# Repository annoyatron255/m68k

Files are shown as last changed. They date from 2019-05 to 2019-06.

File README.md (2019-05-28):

# m68k
A [Motorola 68000](https://en.wikipedia.org/wiki/Motorola_68000) computer. It uses a Lattice FPGA to control the CPU and interface with the peripherals. It is designed to be standalone, with a PS/2 port for input and a VGA port for display output. 
## Contributors
* [Avery Bartnik](https://github.com/Jythonscript)
  * [Assembly Programming](https://github.com/annoyatron255/m68k/blob/master/src/init.s)
  * README
* [Erik Duxstad](https://github.com/eduxstad)
  * Schematic
  * PCB Layout
  * Ordering PCB
* [Jack Sweeney](https://github.com/annoyatron255)
  * Schematic
  * Assembly Programming
  * FPGA Verilog
  * Simulation
* [Michael Wagner](https://github.com/MDW01)
  * Schematic
  * PCB Layout
  * Ordering Parts
## What We Did
1. Design schematic for 68000 computer
2. Design and layout the PCB
3. Order the PCB and parts
4. Wrote Verilog HDL for the FPGA
5. Set up a RTL simulator for the whole computer design
6. Wrote an assembly program in the simulator that displays text using the serial port
## What We Will Do
1. Solder the parts to the PCB
2. Synthesize the verilog and flash to SPI Flash to configure FPGA
3. Interface with the board via the serial port
4. Run programs on real hardware!
## Long-Term Improvements
1. Enable on-board SRAM
2. Configure toolchain to allow for C programming
3. Add scheduling interrupt
4. Install Linux
5. Set up VGA peripheral
6. Set up PS/2 peripheral
7. Set up SD Card peripheral
8. Make MMU on FPGA for Linux
## Gallery
### PCB
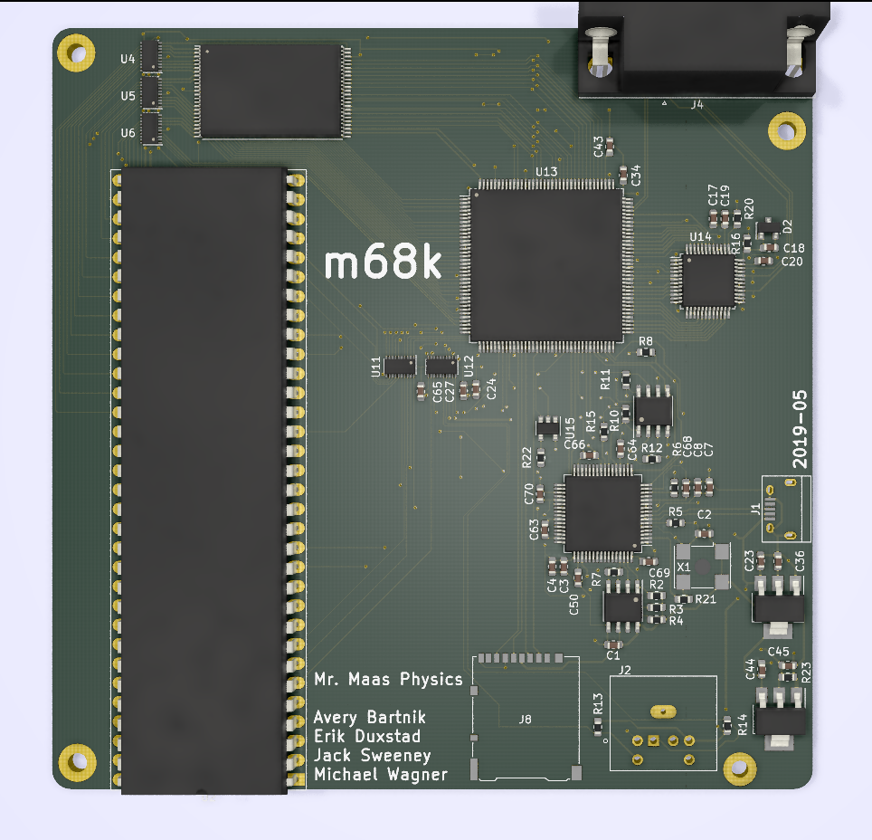
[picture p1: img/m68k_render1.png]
PCB Render Front

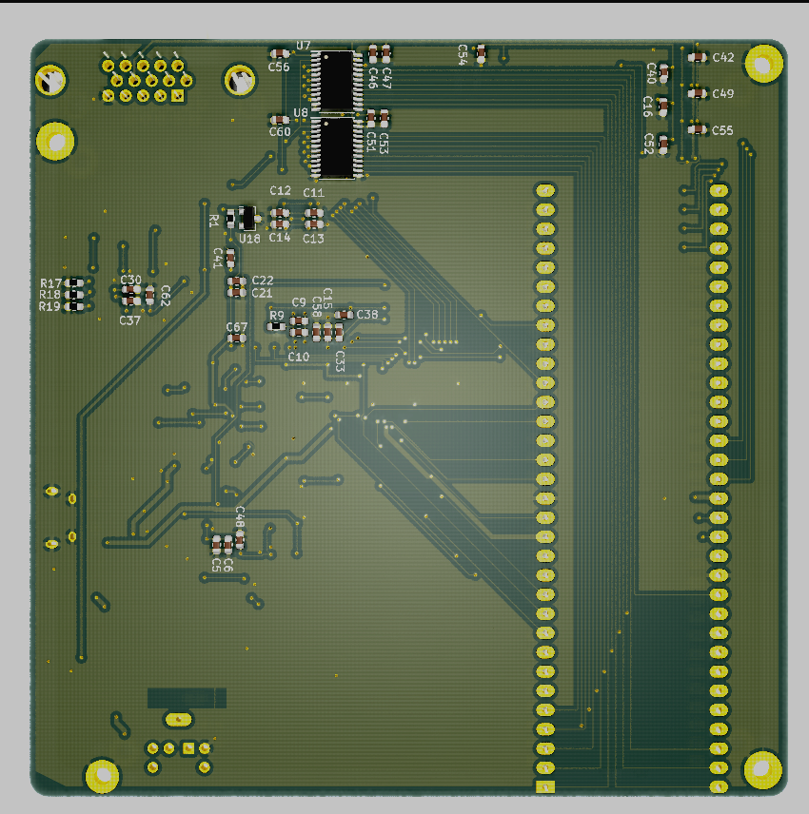
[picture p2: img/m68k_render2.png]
PCB Render Back

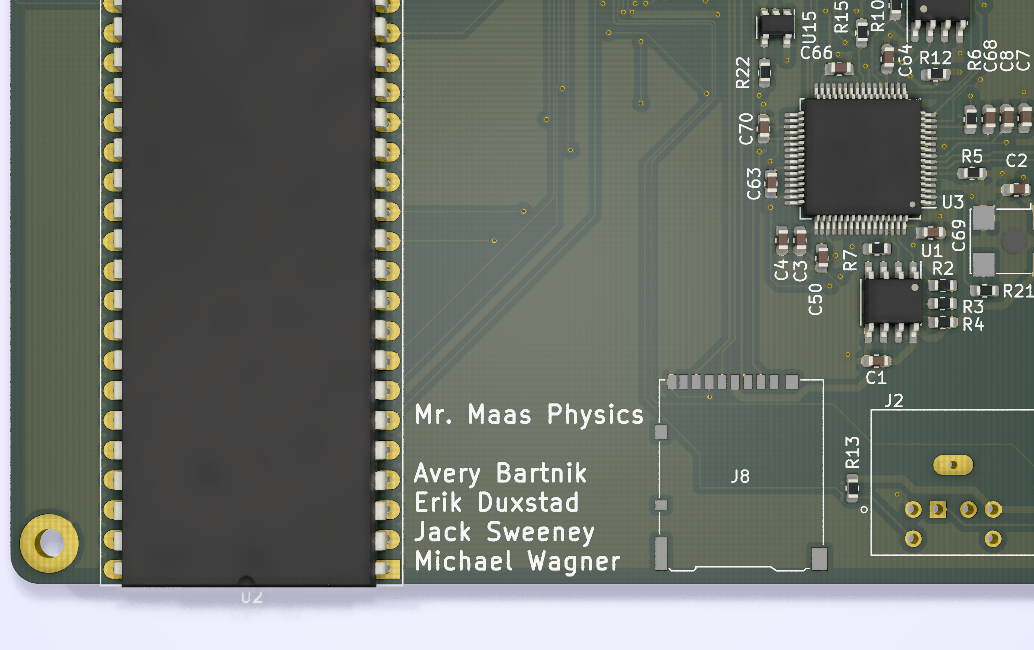
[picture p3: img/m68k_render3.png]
PCB Render Names

### PCB Layout 
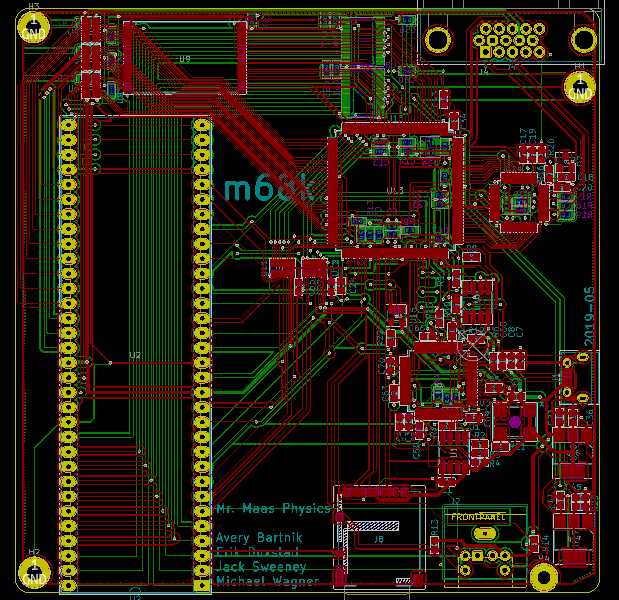
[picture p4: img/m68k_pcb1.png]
PCB Layout Editor Overview

### FPGA
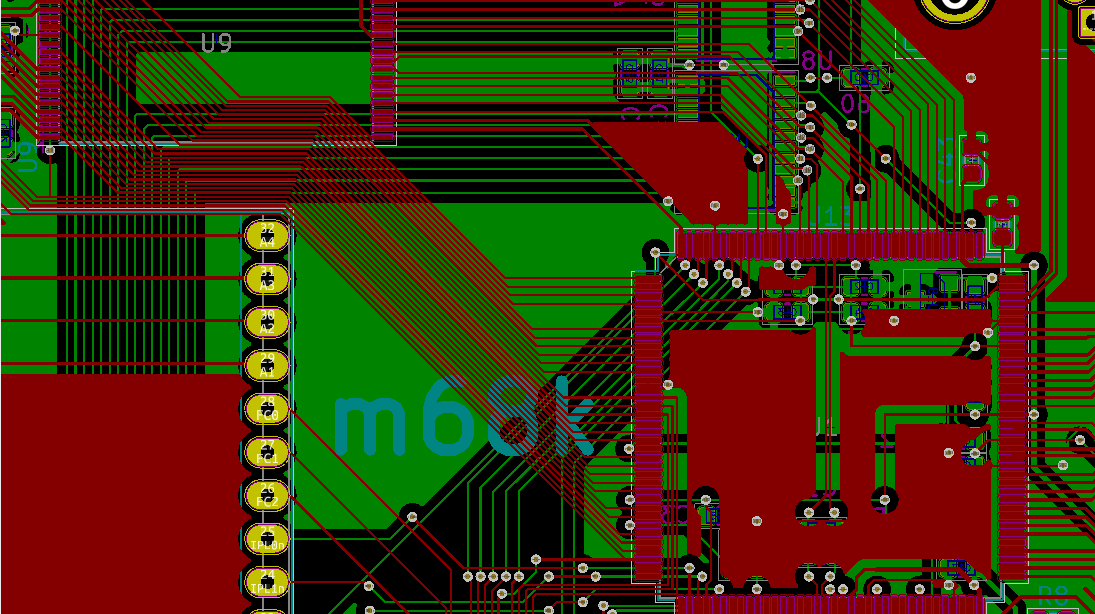
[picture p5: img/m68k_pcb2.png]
PCB Layout Editor FPGA

### SRAM
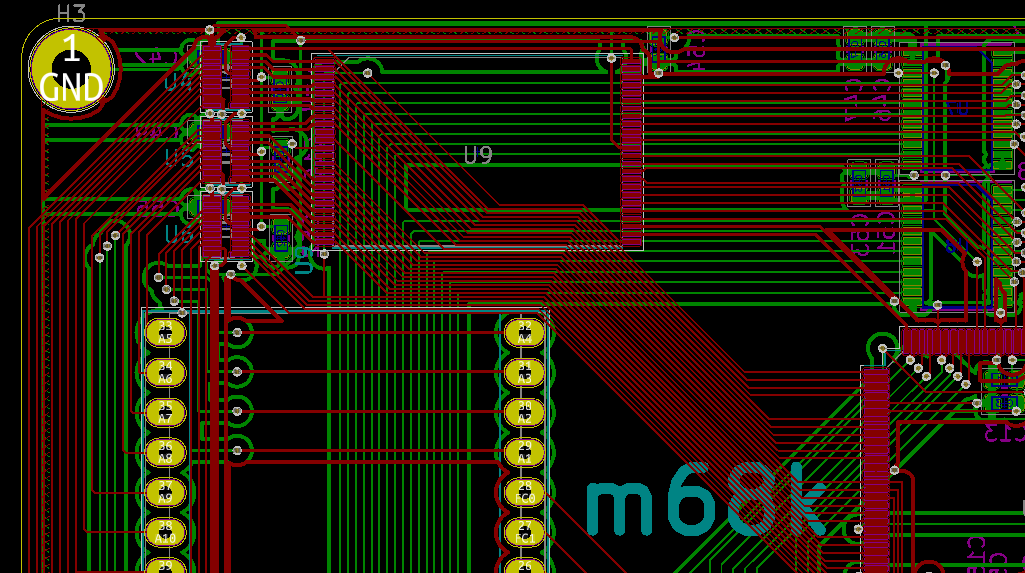
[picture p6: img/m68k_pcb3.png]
PCB Layout Editor SRAM

### Schematic
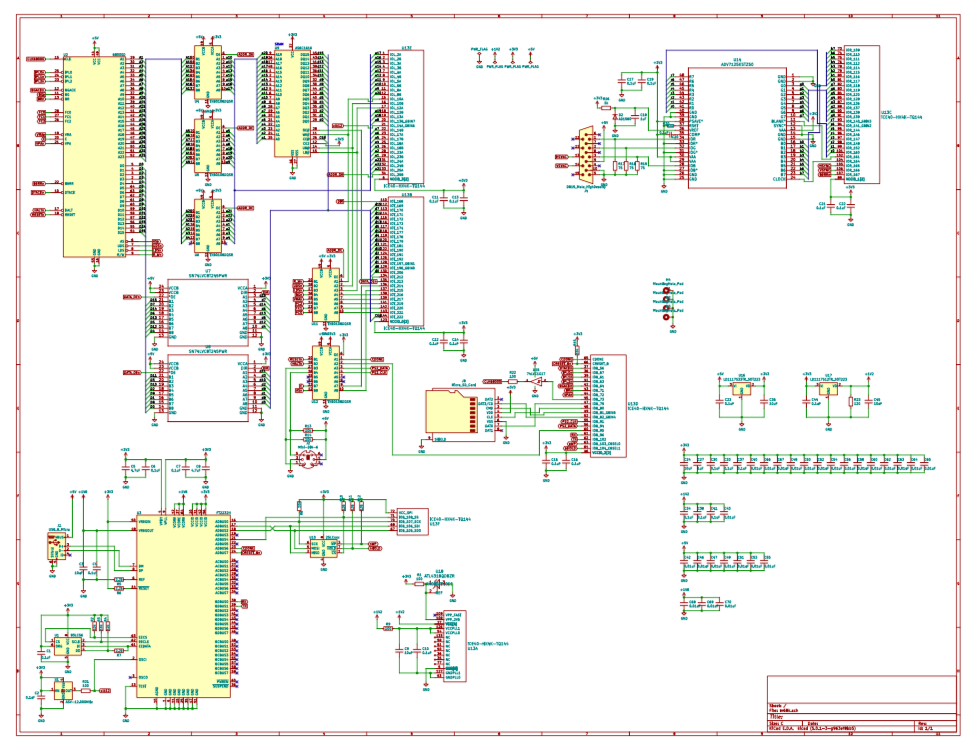
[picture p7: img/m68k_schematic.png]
PCB Schematic


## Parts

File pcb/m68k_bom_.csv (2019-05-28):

Component | Description | Value | Footprint | Quantity Per PCB | Digikey | Ordered
1 | Unpolarized capacitor | 10000 pF | 0603 | 25 | _1276-1132-1-ND_
2 | Unpolarized capacitor | 0.1uF | 0603 | 25 | _1276-1006-1-ND_
3 | Unpolarized capacitor | 10uF | 0603 | 5 | _1276-1192-1-ND_
4 | Unpolarized capacitor | 1uF | 0603 | 2 | 1276-1102-1-ND_
5 | Unpolarized capacitor | 4.7uF | 0603 | 2 | _1276-1044-1-ND_
6 | Diode | AD1580 | SOT-23 | 1 | _AD1580ARTZ-REEL7CT-ND_
7 | Micro SD Card Socket | Micro_SD_Card | DM3AT-SF-PEJM5 | 1 | _HR1964CT-ND_
8 | Mini-DIN-6 | Mini-DIN-6 | CUI_MD-60S | 1 | _CP-2460-ND_
9 | USB_B_Micro | USB_B_Micro | USB_Micro-B | 1 | _609-4618-1-ND_
10 | Resistor | 100 | 0603 | 4 | 311-100HRCT-ND
11 | Resistor | 10k | 0603 | 10 | N/A | 0
12 | Resistor | 120 | 0603 | 1 | 311-120HRCT-ND
13 | Resistor | 1k | 0603 | 1 | N/A | 0
14 | Resistor | 2.2k | 0603 | 3 | 311-2.20KHRCT-ND
15 | Resistor | 530 | 0603 | 1 | _311-536HRCT-ND_
16 | Resistor | 75 | 0603 | 3 | 311-75.0HRCT-ND
17 | SPI Serial EEPROM, DIP-8/SOIC-8/TSSOP-8 | 25LCxxx | SOIC-8_3.9x4.9mm_P1.27mm | 1 | _W25Q128JVSIMCT-ND_
18 | 68000D | 68000D | DIP-64_W22.86mm_Socket_LongPads | 1 | N/A | 0
19 | Single Schmitt Buffer Gate, Low-Voltage CMOS | 74LVC1G17 | SOT-23-5 | 1 | _296-35948-1-ND_
20 | Serial EEPROM, 93 Series, with ORG Pin, 2.5V, DIP-8/SOIC-8 | 93LC56 | SOIC-8_3.9x4.9mm_P1.27mm | 1 | _93LC56BT-I/SNCT-ND_
21 |  | ADV7125KSTZ50 | LQFP-48_7x7mm_P0.5mm | 1 | _ADV7125KSTZ50-ND_
22 |  | AS6C1616 | TSOP-I-48_18.4x12mm_P0.5mm | 1 | _1450-1022-ND_
23 |  | ATL431BQDBZR | SOT-23 | 1 | _296-44371-1-ND_
24 | FT2232Hx, Hi Speed Double Channel USB UART/FIFO, LQFP/QFN-64 | FT2232H | LQFP-64_10x10mm_P0.5mm | 1 | _768-1347-ND_
25 | 800mA Fixed Low Drop Positive Voltage Regulator, Fixed Output 1.2V, SOT-223 | LD1117S12TR_SOT223 | SOT-223-3_TabPin2 | 1 | _497-4240-1-ND_
26 | 800mA Fixed Low Drop Positive Voltage Regulator, Fixed Output 3.3V, SOT-223 | LD1117S33TR_SOT223 | SOT-223-3_TabPin2 | 1 | _497-1242-1-ND_
27 |  | SN74LVC8T245PWR | TSSOP-24_4.4x7.8mm_P0.65mm | 2 | _296-18593-1-ND_
28 |  | TXB0108DQSR | USON-20_2x4mm_P0.4mm | 5 | _296-27217-1-ND_
29 |  | iCE40-HX4K-TQ144 | TQFP-144_20x20mm_P0.5mm | 1 | _220-1572-ND_
30 | 3.3V HCMOS SMD Crystal Clock Oscillator, Abracon | ASV-12.000MHz | Oscillator_SMD_Abracon_ASV-4Pin_7.0x5.1mm | 1 | _535-9309-1-ND_

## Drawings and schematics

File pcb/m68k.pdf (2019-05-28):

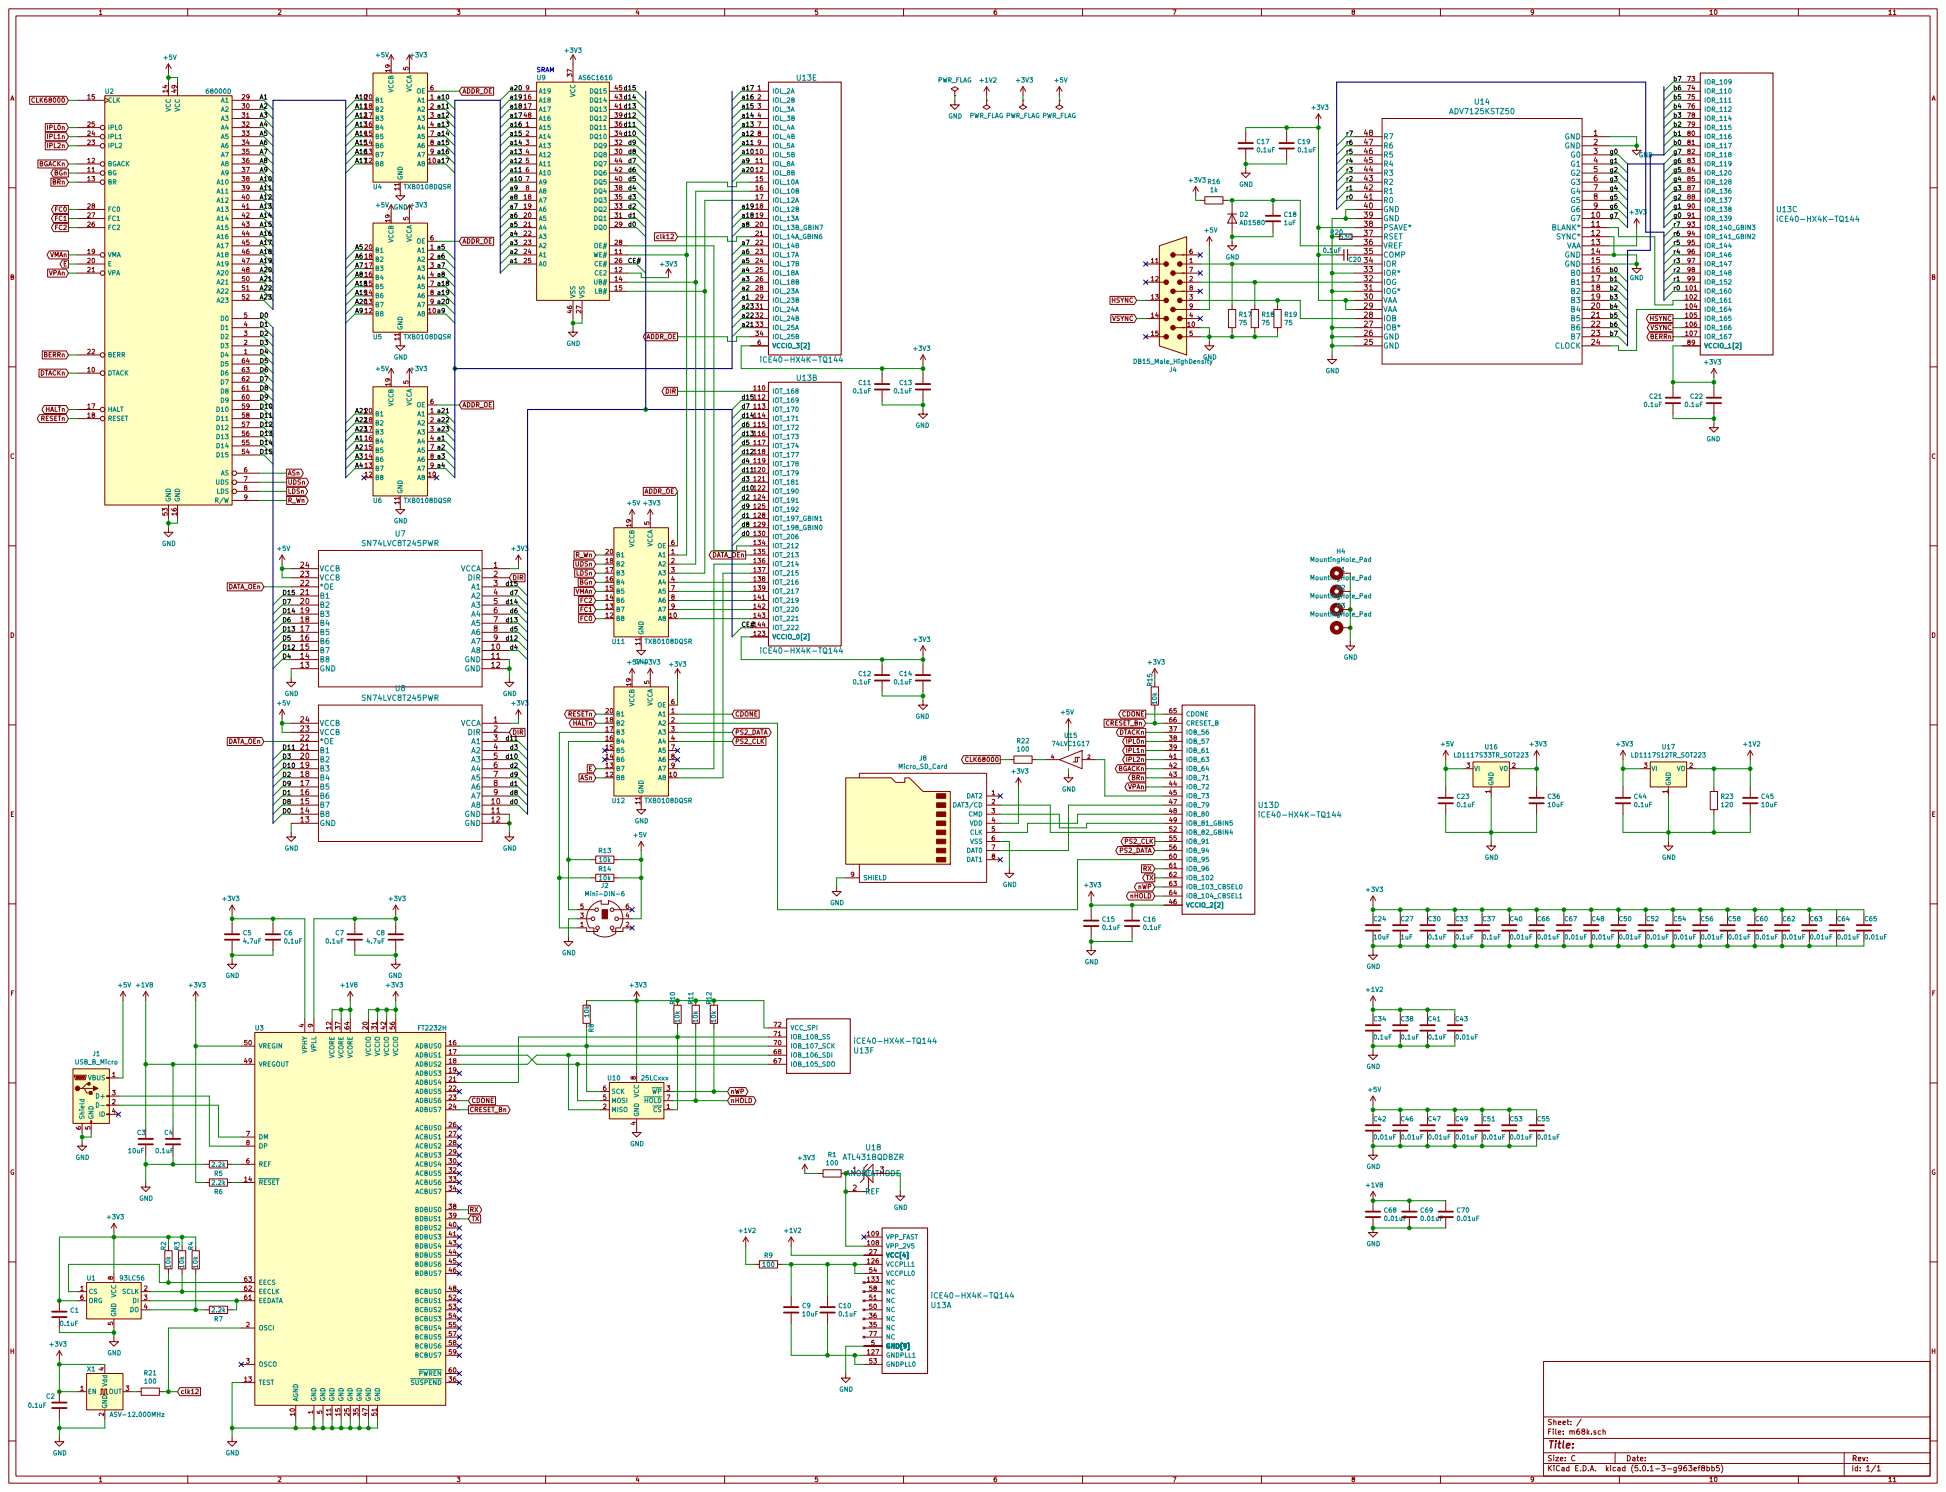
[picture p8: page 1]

IPL2n BGACKn BGn BRn FC0 FC1 FC2 VMAnE

1 AGND 10 GND 11 VCORE 12 TEST 13 RESET 14 GND 15 ADBUS0 16 ADBUS1 17 ADBUS2 18 ADBUS3 19 OSCI 2 VCCIO 20 ADBUS4 21 ADBUS5 22 ADBUS6 23 ADBUS7 24 GND 25 ACBUS0 26 ACBUS1 27 ACBUS2 28 ACBUS3 29 OSCO 3 ACBUS4 30 VCCIO 31 ACBUS5 32 ACBUS6 33 ACBUS7 34 GND 35 SUSPEND 36 VCORE 37 BDBUS0 38 BDBUS1 39 VPHY

4 BDBUS2 40 BDBUS3 41 VCCIO 42 BDBUS4 43 BDBUS5 44 BDBUS6 45 BDBUS7 46 GND 47 BCBUS0 48 VREGOUT 49 GND

5 VREGIN 50 GND 51 BCBUS1 52 BCBUS2 53 BCBUS3 54 BCBUS4 55 VCCIO 56 BCBUS5 57 BCBUS6 58 BCBUS7 59 REF 6 PWREN 60 EEDATA 61 EECLK 62 EECS 63 VCORE 64 DM 7 DP 8 VPLL

4 MOSI 5 SCK 6 HOLD VCC 7 U10 8

Id: 1/1 Title: File: m68k.sch Sheet: /

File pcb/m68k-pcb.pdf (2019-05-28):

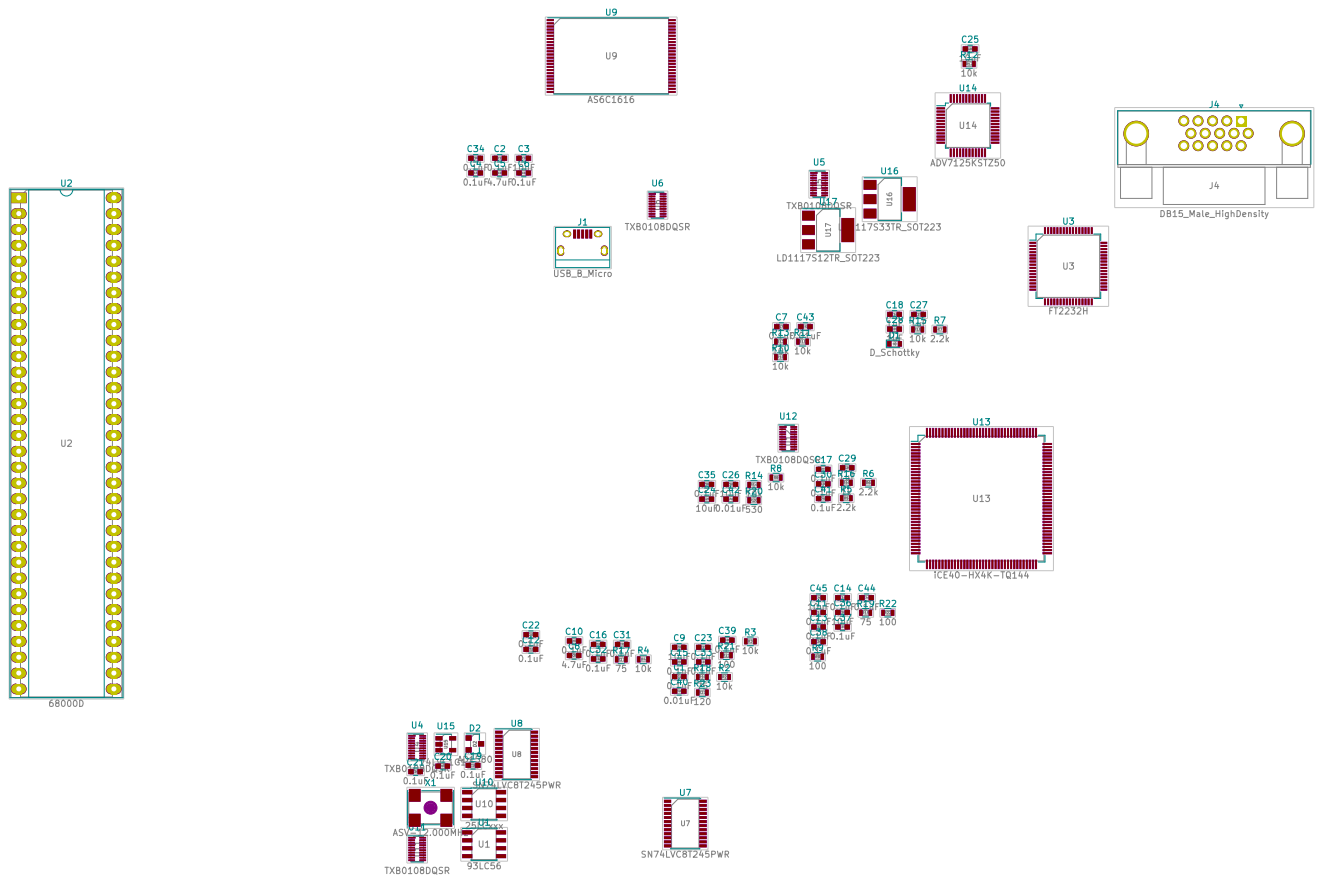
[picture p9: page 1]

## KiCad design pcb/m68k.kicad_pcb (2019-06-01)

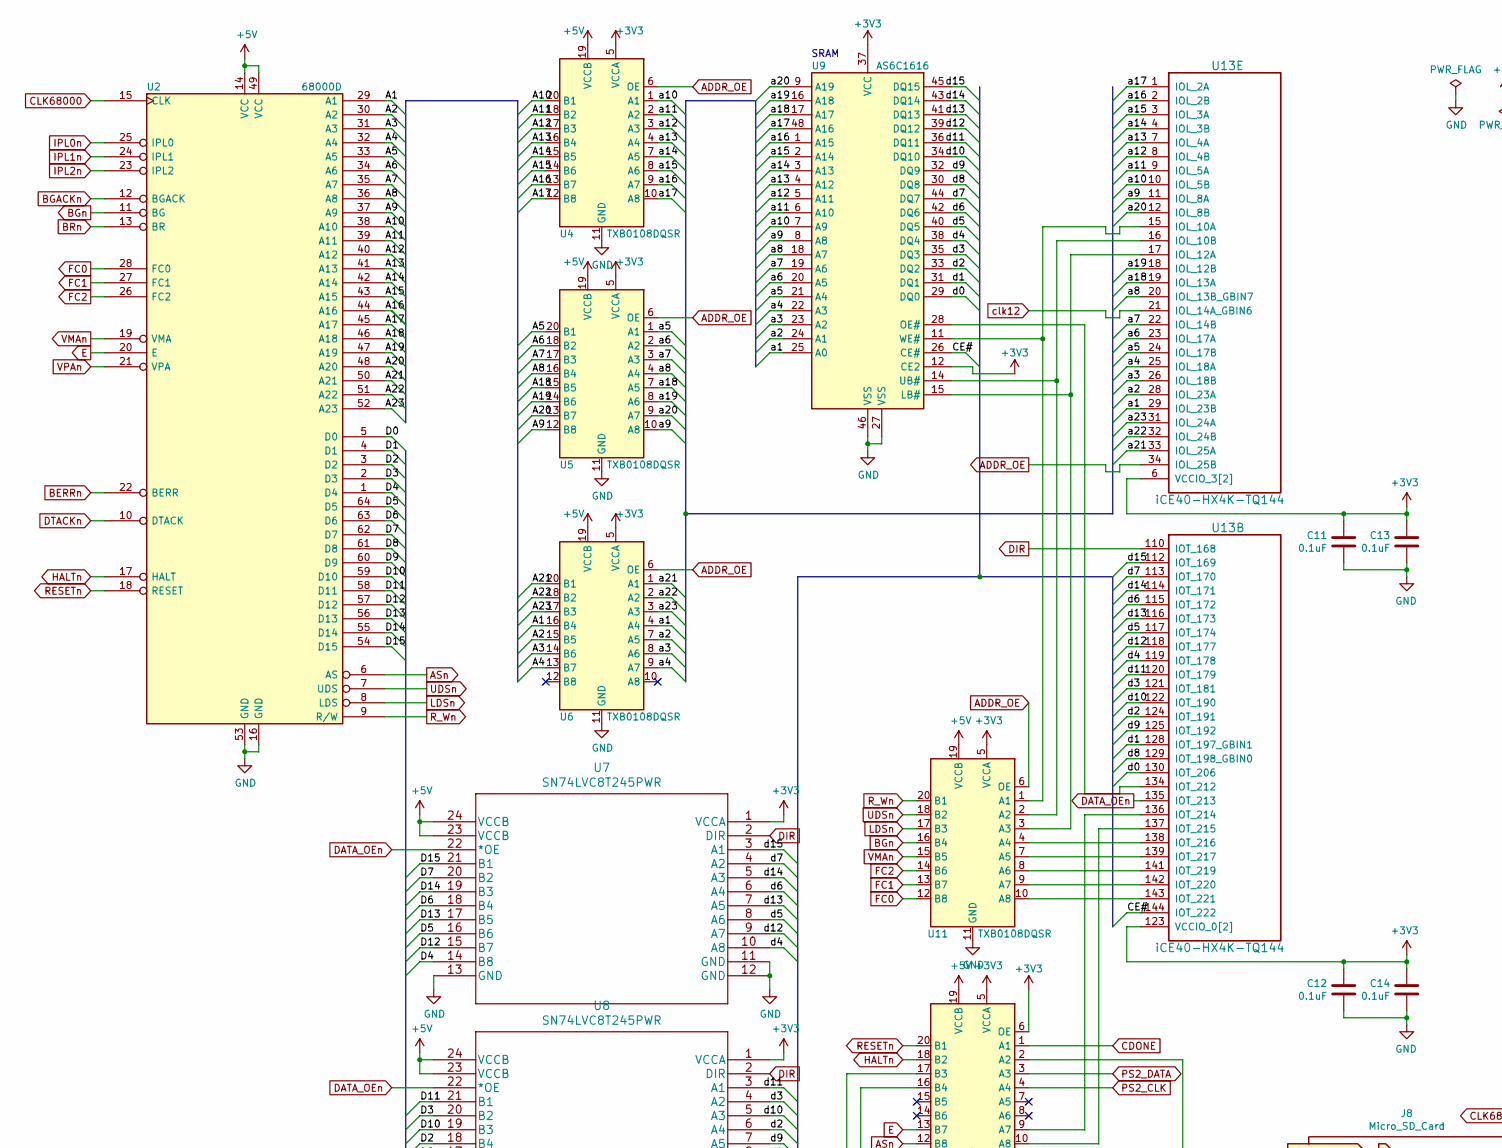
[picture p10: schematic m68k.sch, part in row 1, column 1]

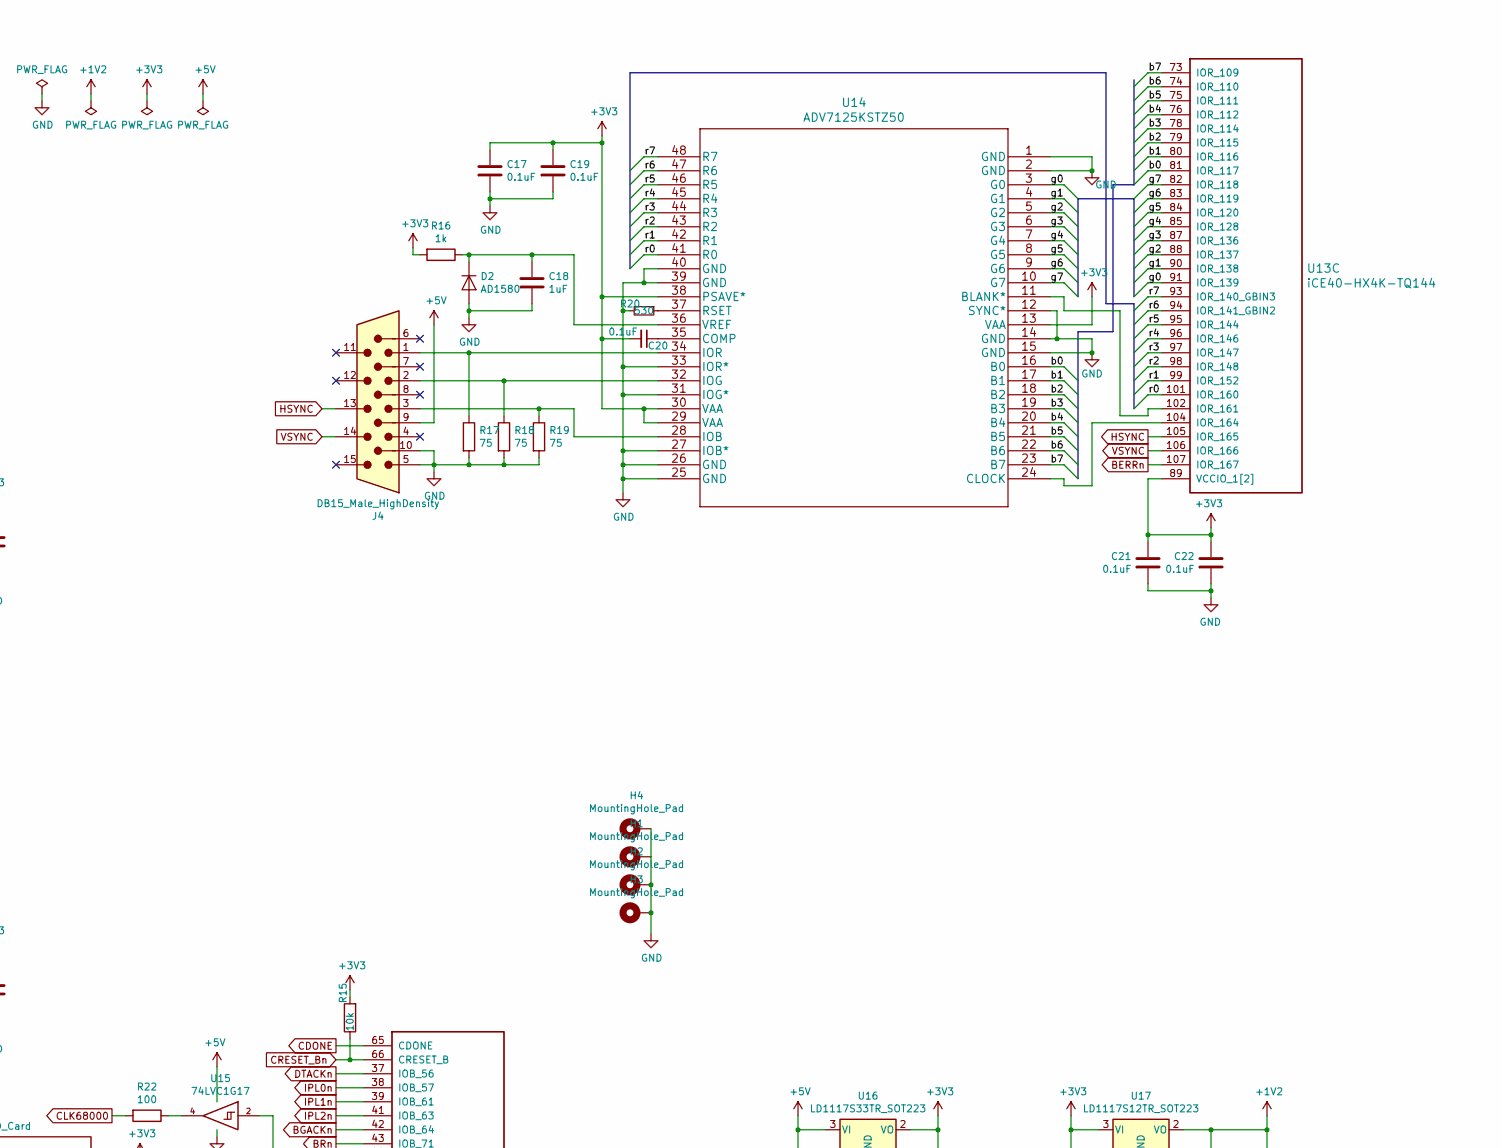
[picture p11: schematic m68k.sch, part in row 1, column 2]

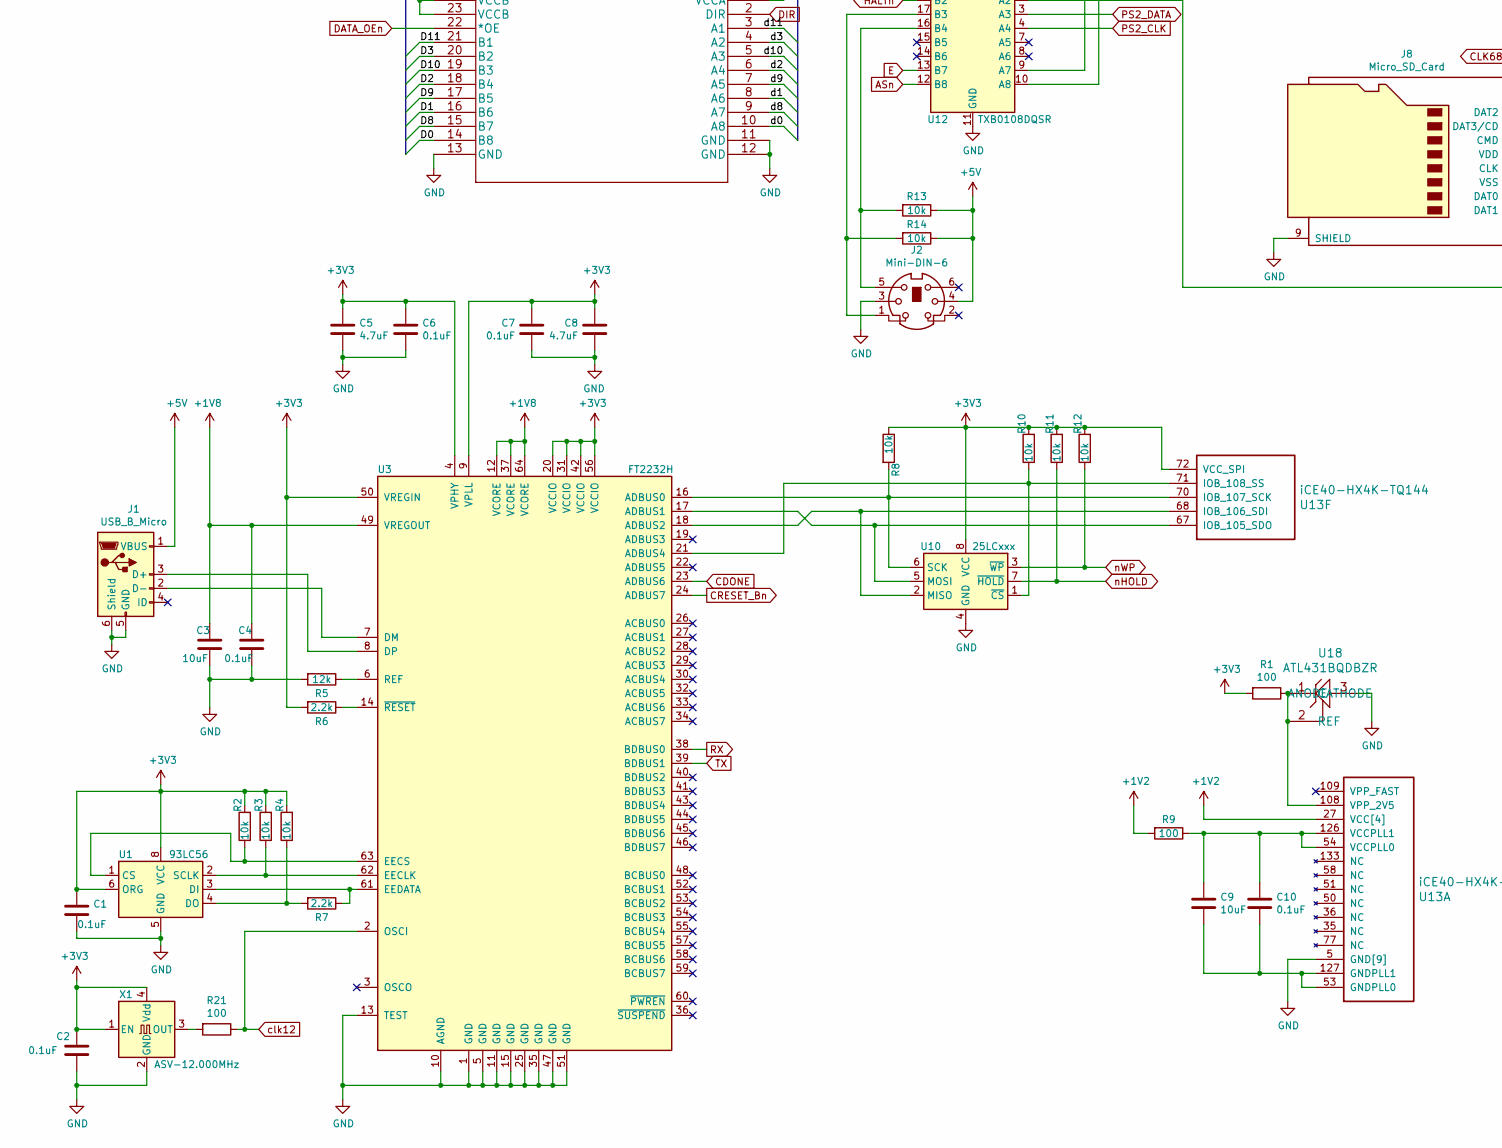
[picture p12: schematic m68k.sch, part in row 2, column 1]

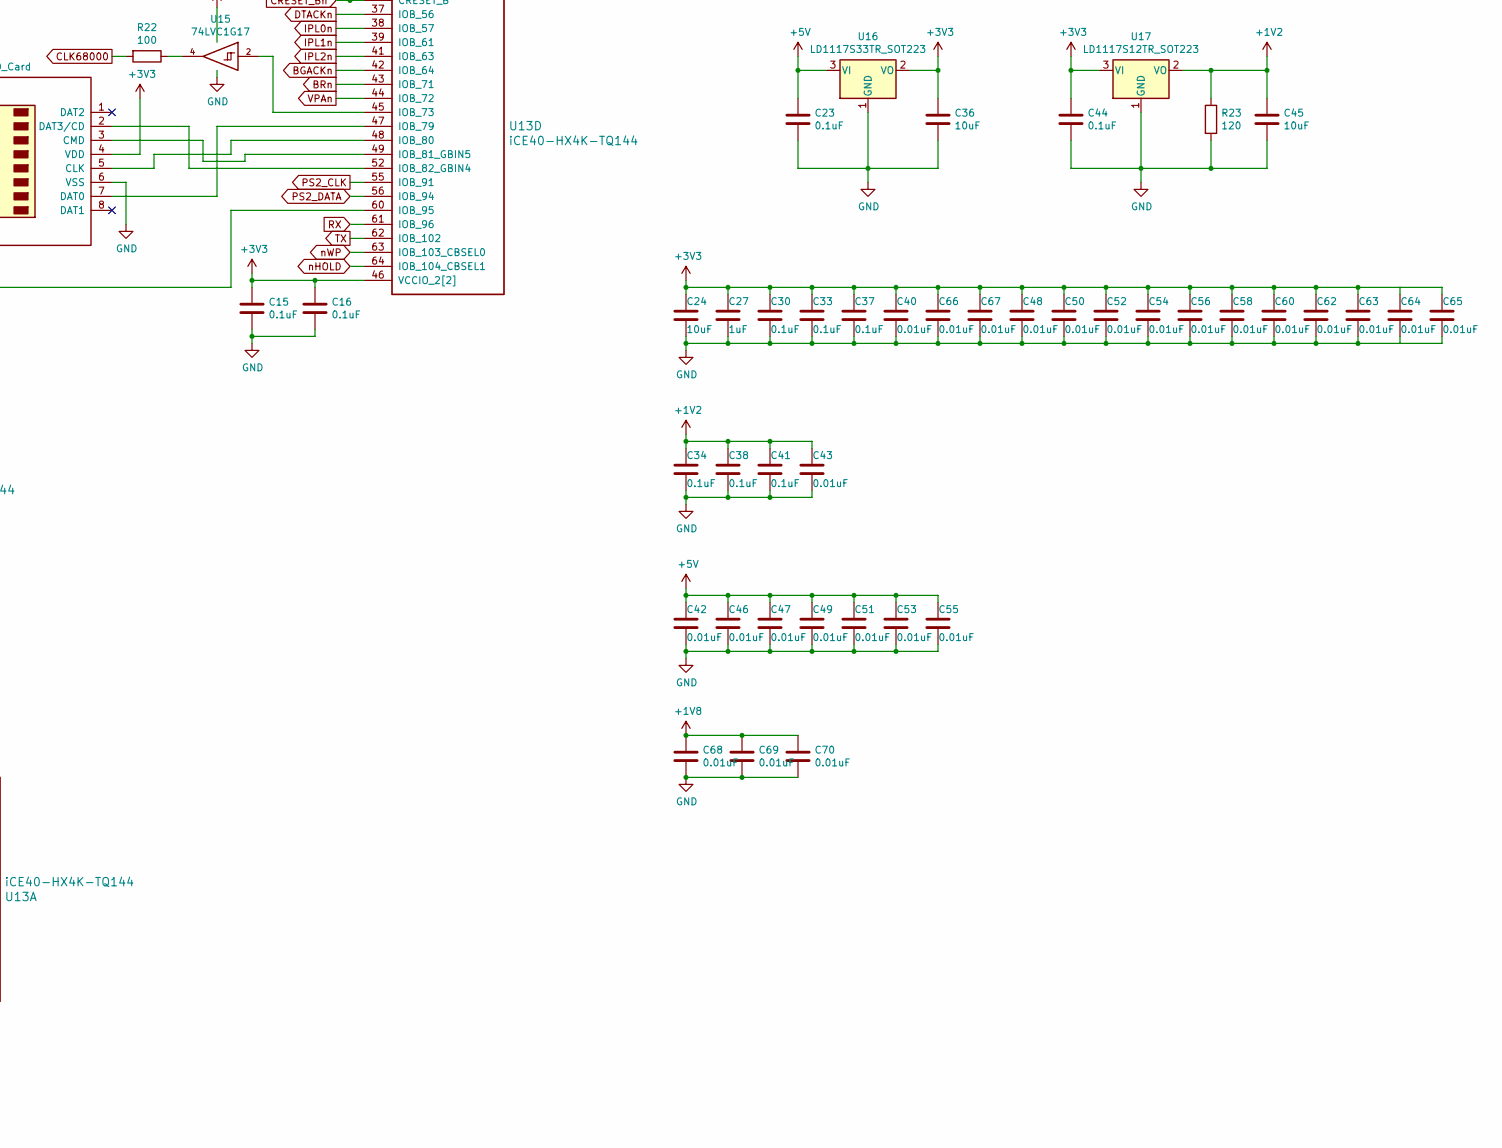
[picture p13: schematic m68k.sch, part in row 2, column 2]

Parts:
C1, C2, C4, C6, C7, C10, C11, C12, C13, C14, C15, C16, C17, C19, C20, C21, C22, C23, C30, C33, C34, C37, C38, C41, C44: 0.1uF; C_0603_1608Metric
C3, C9, C24, C36, C45: 10uF; C_0603_1608Metric
C5, C8: 4.7uF; C_0603_1608Metric
C18, C27: 1uF; C_0603_1608Metric
C40, C42, C43, C46, C47, C48, C49, C50, C51, C52, C53, C54, C55, C56, C58, C60, C62, C63, C64, C65, C66, C67, C68, C69, C70: 0.01uF; C_0603_1608Metric
D2: AD1580; SOT-23
H1, H2, H3, H4: MountingHole_Pad; MountingHole_2.5mm_Pad
J1: USB_B_Micro; USB_Micro-B
J2: Mini-DIN-6; CUI_MD-60S
J4: DB15_Male_HighDensity; DSUB-15-HD_Female_Horizontal_P2.29x1.98mm_EdgePinOffset3.03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
J8: Micro_SD_Card; microSD_HC_Hirose_DM3AT-SF-PEJM5
R1, R9, R21, R22: 100; R_0603_1608Metric
R2, R3, R4, R8, R10, R11, R12, R13, R14, R15: 10k; R_0603_1608Metric
R5: 12k; R_0603_1608Metric
R6, R7: 2.2k; R_0603_1608Metric
R16: 1k; R_0603_1608Metric
R17, R18, R19: 75; R_0603_1608Metric
R20: 530; R_0603_1608Metric
R23: 120; R_0603_1608Metric
U1: 93LC56; SOIC-8_3.9x4.9mm_P1.27mm
U2: 68000D; DIP-64_W22.86mm_Socket_LongPads
U3: FT2232H; LQFP-64_10x10mm_P0.5mm
U4, U5, U6, U11, U12: TXB0108DQSR; USON-20_2x4mm_P0.4mm
U7, U8: SN74LVC8T245PWR; TSSOP-24_4.4x7.8mm_P0.65mm
U9: AS6C1616; TSOP-I-48_18.4x12mm_P0.5mm
U10: 25LCxxx; SOIC-8_3.9x4.9mm_P1.27mm
U13: iCE40-HX4K-TQ144; TQFP-144_20x20mm_P0.5mm
U14: ADV7125KSTZ50; LQFP-48_7x7mm_P0.5mm
U15: 74LVC1G17; SOT-23-5
U16: LD1117S33TR_SOT223; SOT-223-3_TabPin2
U17: LD1117S12TR_SOT223; SOT-223-3_TabPin2
U18: ATL431BQDBZR; SOT-23
X1: ASV-12.000MHz; Oscillator_SMD_Abracon_ASV-4Pin_7.0x5.1mm

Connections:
+1V2: C34.1, C38.1, C41.1, C43.1, C45.1, R9.2, R23.1, U13.27 (VCC[4]), U13.40 (VCC[4]), U13.92 (VCC[4]), U13.111 (VCC[4]), U17.2 (VO)
+1V8: C3.1, C4.1, C68.1, C69.1, C70.1, U3.12 (VCORE), U3.37 (VCORE), U3.49 (VREGOUT), U3.64 (VCORE)
+3V3: C1.1, C2.1, C5.1, C6.1, C7.1, C8.1, C11.1, C12.1, C13.1, C14.1, C15.1, C16.1, C17.1, C19.1, C20.2, C21.1, C22.1, C24.1, C27.1, C30.1, C33.1, C36.1, C37.1, C40.1, C44.1, C48.1, C50.1, C52.1, C54.1, C56.1, C58.1, C60.1, C62.1, C63.1, C64.1, C65.1, C66.1, C67.1, J8.4 (VDD), R1.2, R2.2, R3.2, R4.2, R6.2, R8.1, R10.2, R11.2, R12.2, R15.2, R16.2, U1.6 (ORG), U1.8 (VCC), U3.4 (VPHY), U3.9 (VPLL), U3.20 (VCCIO), U3.31 (VCCIO), U3.42 (VCCIO), U3.50 (VREGIN), U3.56 (VCCIO), U4.5 (VCCA), U5.5 (VCCA), U6.5 (VCCA), U7.1 (VCCA), U8.1 (VCCA), U9.12 (CE2), U9.37 (VCC), U10.8 (VCC), U11.5 (VCCA), U12.5 (VCCA), U12.6 (OE), U13.6 (VCCIO_3[2]), U13.30 (VCCIO_3[2]), U13.46 (VCCIO_2[2]), U13.57 (VCCIO_2[2]), U13.72 (VCC_SPI), U13.89 (VCCIO_1[2]), U13.100 (VCCIO_1[2]), U13.123 (VCCIO_0[2]), U13.131 (VCCIO_0[2]), U14.13 (VAA), U14.29 (VAA), U14.30 (VAA), U14.38 (PSAVE*), U16.2 (VO), U17.3 (VI), X1.1 (EN), X1.4 (Vdd)
+5V: C23.1, C42.1, C46.1, C47.1, C49.1, C51.1, C53.1, C55.1, J1.1 (VBUS), J2.4, J4.9, R13.1, R14.1, U2.14 (VCC), U2.49 (VCC), U4.19 (VCCB), U5.19 (VCCB), U6.19 (VCCB), U7.23 (VCCB), U7.24 (VCCB), U8.23 (VCCB), U8.24 (VCCB), U11.19 (VCCB), U12.19 (VCCB), U15.5 (VCC), U16.3 (VI)
/A1: U2.29 (A1), U6.16 (B4)
/A2: U2.30 (A2), U6.15 (B5)
/A3: U2.31 (A3), U6.14 (B6)
/A4: U2.32 (A4), U6.13 (B7)
/A5: U2.33 (A5), U5.20 (B1)
/A6: U2.34 (A6), U5.18 (B2)
/A7: U2.35 (A7), U5.17 (B3)
/A8: U2.36 (A8), U5.16 (B4)
/A9: U2.37 (A9), U5.12 (B8)
/A10: U2.38 (A10), U4.20 (B1)
/A11: U2.39 (A11), U4.18 (B2)
/A12: U2.40 (A12), U4.17 (B3)
/A13: U2.41 (A13), U4.16 (B4)
/A14: U2.42 (A14), U4.15 (B5)
/A15: U2.43 (A15), U4.14 (B6)
/A16: U2.44 (A16), U4.13 (B7)
/A17: U2.45 (A17), U4.12 (B8)
/A18: U2.46 (A18), U5.15 (B5)
/A19: U2.47 (A19), U5.14 (B6)
/A20: U2.48 (A20), U5.13 (B7)
/A21: U2.50 (A21), U6.20 (B1)
/A22: U2.51 (A22), U6.18 (B2)
/A23: U2.52 (A23), U6.17 (B3)
/CE#: U9.26 (CE#), U13.144 (IOT_222)
/D0: U2.5 (D0), U8.14 (B8)
/D1: U2.4 (D1), U8.16 (B6)
/D2: U2.3 (D2), U8.18 (B4)
/D3: U2.2 (D3), U8.20 (B2)
/D4: U2.1 (D4), U7.14 (B8)
/D5: U2.64 (D5), U7.16 (B6)
/D6: U2.63 (D6), U7.18 (B4)
/D7: U2.62 (D7), U7.20 (B2)
/D8: U2.61 (D8), U8.15 (B7)
/D9: U2.60 (D9), U8.17 (B5)
/D10: U2.59 (D10), U8.19 (B3)
/D11: U2.58 (D11), U8.21 (B1)
/D12: U2.57 (D12), U7.15 (B7)
/D13: U2.56 (D13), U7.17 (B5)
/D14: U2.55 (D14), U7.19 (B3)
/D15: U2.54 (D15), U7.21 (B1)
/a1: U6.4 (A4), U9.25 (A0), U13.29 (IOL_23B)
/a2: U6.7 (A5), U9.24 (A1), U13.28 (IOL_23A)
/a3: U6.8 (A6), U9.23 (A2), U13.26 (IOL_18B)
/a4: U6.9 (A7), U9.22 (A3), U13.25 (IOL_18A)
/a5: U5.1 (A1), U9.21 (A4), U13.24 (IOL_17B)
/a6: U5.2 (A2), U9.20 (A5), U13.23 (IOL_17A)
/a7: U5.3 (A3), U9.19 (A6), U13.22 (IOL_14B)
/a8: U5.4 (A4), U9.18 (A7), U13.20 (IOL_13B_GBIN7)
/a9: U5.10 (A8), U9.8 (A8), U13.11 (IOL_8A)
/a10: U4.1 (A1), U9.7 (A9), U13.10 (IOL_5B)
/a11: U4.2 (A2), U9.6 (A10), U13.9 (IOL_5A)
/a12: U4.3 (A3), U9.5 (A11), U13.8 (IOL_4B)
/a13: U4.4 (A4), U9.4 (A12), U13.7 (IOL_4A)
/a14: U4.7 (A5), U9.3 (A13), U13.4 (IOL_3B)
/a15: U4.8 (A6), U9.2 (A14), U13.3 (IOL_3A)
/a16: U4.9 (A7), U9.1 (A15), U13.2 (IOL_2B)
/a17: U4.10 (A8), U9.48 (A16), U13.1 (IOL_2A)
/a18: U5.7 (A5), U9.17 (A17), U13.19 (IOL_13A)
/a19: U5.8 (A6), U9.16 (A18), U13.18 (IOL_12B)
/a20: U5.9 (A7), U9.9 (A19), U13.12 (IOL_8B)
/a21: U6.1 (A1), U13.33 (IOL_25A)
/a22: U6.2 (A2), U13.32 (IOL_24B)
/a23: U6.3 (A3), U13.31 (IOL_24A)
/b0: U13.81 (IOR_117), U14.16 (B0)
/b1: U13.80 (IOR_116), U14.17 (B1)
/b2: U13.79 (IOR_115), U14.18 (B2)
/b3: U13.78 (IOR_114), U14.19 (B3)
/b4: U13.76 (IOR_112), U14.20 (B4)
/b5: U13.75 (IOR_111), U14.21 (B5)
/b6: U13.74 (IOR_110), U14.22 (B6)
/b7: U13.73 (IOR_109), U14.23 (B7)
/d0: U8.10 (A8), U9.29 (DQ0), U13.130 (IOT_206)
/d1: U8.8 (A6), U9.31 (DQ1), U13.128 (IOT_197_GBIN1)
/d2: U8.6 (A4), U9.33 (DQ2), U13.124 (IOT_191)
/d3: U8.4 (A2), U9.35 (DQ3), U13.121 (IOT_181)
/d4: U7.10 (A8), U9.38 (DQ4), U13.119 (IOT_178)
/d5: U7.8 (A6), U9.40 (DQ5), U13.117 (IOT_174)
/d6: U7.6 (A4), U9.42 (DQ6), U13.115 (IOT_172)
/d7: U7.4 (A2), U9.44 (DQ7), U13.113 (IOT_170)
/d8: U8.9 (A7), U9.30 (DQ8), U13.129 (IOT_198_GBIN0)
/d9: U8.7 (A5), U9.32 (DQ9), U13.125 (IOT_192)
/d10: U8.5 (A3), U9.34 (DQ10), U13.122 (IOT_190)
/d11: U8.3 (A1), U9.36 (DQ11), U13.120 (IOT_179)
/d12: U7.9 (A7), U9.39 (DQ12), U13.118 (IOT_177)
/d13: U7.7 (A5), U9.41 (DQ13), U13.116 (IOT_173)
/d14: U7.5 (A3), U9.43 (DQ14), U13.114 (IOT_171)
/d15: U7.3 (A1), U9.45 (DQ15), U13.112 (IOT_169)
/g0: U13.91 (IOR_139), U14.3 (G0)
/g1: U13.90 (IOR_138), U14.4 (G1)
/g2: U13.88 (IOR_137), U14.5 (G2)
/g3: U13.87 (IOR_136), U14.6 (G3)
/g4: U13.85 (IOR_128), U14.7 (G4)
/g5: U13.84 (IOR_120), U14.8 (G5)
/g6: U13.83 (IOR_119), U14.9 (G6)
/g7: U13.82 (IOR_118), U14.10 (G7)
/r0: U13.101 (IOR_160), U14.41 (R0)
/r1: U13.99 (IOR_152), U14.42 (R1)
/r2: U13.98 (IOR_148), U14.43 (R2)
/r3: U13.97 (IOR_147), U14.44 (R3)
/r4: U13.96 (IOR_146), U14.45 (R4)
/r5: U13.95 (IOR_144), U14.46 (R5)
/r6: U13.94 (IOR_141_GBIN2), U14.47 (R6)
/r7: U13.93 (IOR_140_GBIN3), U14.48 (R7)
ADDR_OE: U4.6 (OE), U5.6 (OE), U6.6 (OE), U11.6 (OE), U13.34 (IOL_25B)
ASn: U2.6 (AS), U12.12 (B8)
BERRn: U2.22 (BERR), U13.107 (IOR_167)
BGACKn: U2.12 (BGACK), U13.42 (IOB_64)
BGn: U2.11 (BG), U11.16 (B4)
BRn: U2.13 (BR), U13.43 (IOB_71)
CDONE: U3.23 (ADBUS6), U12.1 (A1), U13.65 (CDONE)
CLK68000: R22.2, U2.15 (CLK)
CRESET_Bn: R15.1, U3.24 (ADBUS7), U13.66 (CRESET_B)
DATA_OEn: U7.22 (*OE), U8.22 (*OE), U13.135 (IOT_213)
DIR: U7.2 (DIR), U8.2 (DIR), U13.110 (IOT_168)
DTACKn: U2.10 (DTACK), U13.37 (IOB_56)
E: U2.20 (E), U12.13 (B7)
FC0: U2.28 (FC0), U11.12 (B8)
FC1: U2.27 (FC1), U11.13 (B7)
FC2: U2.26 (FC2), U11.14 (B6)
GND: C1.2, C2.2, C3.2, C4.2, C5.2, C6.2, C7.2, C8.2, C11.2, C12.2, C13.2, C14.2, C15.2, C16.2, C17.2, C18.2, C19.2, C21.2, C22.2, C23.2, C24.2, C27.2, C30.2, C33.2, C34.2, C36.2, C37.2, C38.2, C40.2, C41.2, C42.2, C43.2, C44.2, C45.2, C46.2, C47.2, C48.2, C49.2, C50.2, C51.2, C52.2, C53.2, C54.2, C55.2, C56.2, C58.2, C60.2, C62.2, C63.2, C64.2, C65.2, C66.2, C67.2, C68.2, C69.2, C70.2, D2.2 (A), H1.1, H2.1, H3.1, H4.1, J1.5 (GND), J1.6 (Shield), J2.3, J4.5, J4.10, J8.6 (VSS), J8.9 (SHIELD), R5.2, R17.2, R18.2, R19.2, R20.2, R23.2, U1.5 (GND), U2.16 (GND), U2.53 (GND), U3.1 (GND), U3.5 (GND), U3.10 (AGND), U3.11 (GND), U3.13 (TEST), U3.15 (GND), U3.25 (GND), U3.35 (GND), U3.47 (GND), U3.51 (GND), U4.11 (GND), U5.11 (GND), U6.11 (GND), U7.11 (GND), U7.12 (GND), U7.13 (GND), U8.11 (GND), U8.12 (GND), U8.13 (GND), U9.27 (VSS), U9.46 (VSS), U10.4 (GND), U11.11 (GND), U12.11 (GND), U13.5 (GND[9]), U13.13 (GND[9]), U13.14 (GND[9]), U13.59 (GND[9]), U13.69 (GND[9]), U13.86 (GND[9]), U13.103 (GND[9]), U13.132 (GND[9]), U13.140 (GND[9]), U14.1 (GND), U14.2 (GND), U14.12 (SYNC*), U14.14 (GND), U14.15 (GND), U14.25 (GND), U14.26 (GND), U14.27 (IOB*), U14.31 (IOG*), U14.33 (IOR*), U14.39 (GND), U14.40 (GND), U15.3 (GND), U16.1 (GND), U17.1 (GND), U18.3 (ANODE), X1.2 (GND)
HALTn: U2.17 (HALT), U12.18 (B2)
HSYNC: J4.13, U13.105 (IOR_165)
IPL0n: U2.25 (IPL0), U13.38 (IOB_57)
IPL1n: U2.24 (IPL1), U13.39 (IOB_61)
IPL2n: U2.23 (IPL2), U13.41 (IOB_63)
LDSn: U2.8 (LDS), U11.17 (B3)
unnamed: C9.1, C10.1, R9.1, U13.54 (VCCPLL0), U13.126 (VCCPLL1)
unnamed: C9.2, C10.2, U13.53 (GNDPLL0), U13.127 (GNDPLL1)
unnamed: C18.1, D2.1 (K), R16.1, U14.36 (VREF)
unnamed: C20.1, U14.35 (COMP)
unnamed: J1.2 (D-), U3.7 (DM)
unnamed: J1.3 (D+), U3.8 (DP)
unnamed: J2.1, R14.2, U12.17 (B3)
unnamed: J2.5, R13.2, U12.16 (B4)
unnamed: J4.1, R17.1, U14.34 (IOR)
unnamed: J4.2, R18.1, U14.32 (IOG)
unnamed: J4.3, R19.1, U14.28 (IOB)
unnamed: J8.2 (DAT3/CD), U13.52 (IOB_82_GBIN4)
unnamed: J8.3 (CMD), U13.49 (IOB_81_GBIN5)
unnamed: J8.5 (CLK), U13.48 (IOB_80)
unnamed: J8.7 (DAT0), U13.47 (IOB_79)
unnamed: R1.1, U13.108 (VPP_2V5), U18.1 (CATHODE), U18.2 (REF)
unnamed: R2.1, U1.1 (CS), U3.63 (EECS)
unnamed: R3.1, U1.2 (SCLK), U3.62 (EECLK)
unnamed: R4.1, R7.2, U1.4 (DO)
unnamed: R5.1, U3.6 (REF)
unnamed: R6.1, U3.14 (~RESET)
unnamed: R7.1, U1.3 (DI), U3.61 (EEDATA)
unnamed: R8.2, U3.16 (ADBUS0), U10.6 (SCK), U13.70 (IOB_107_SCK)
unnamed: R10.1, U3.21 (ADBUS4), U10.1 (~CS), U13.71 (IOB_108_SS)
unnamed: R20.1, U14.37 (RSET)
unnamed: R21.2, X1.3 (OUT)
unnamed: R22.1, U15.4
unnamed: U3.18 (ADBUS2), U10.2 (MISO), U13.68 (IOB_106_SDI)
unnamed: U3.17 (ADBUS1), U10.5 (MOSI), U13.67 (IOB_105_SDO)
unnamed: U9.11 (WE#), U11.1 (A1), U13.15 (IOL_10A)
unnamed: U9.14 (UB#), U11.2 (A2), U13.16 (IOL_10B)
unnamed: U9.15 (LB#), U11.3 (A3), U13.17 (IOL_12A)
unnamed: U11.4 (A4), U13.138 (IOT_216)
unnamed: U11.7 (A5), U13.139 (IOT_217)
unnamed: U11.8 (A6), U13.141 (IOT_219)
unnamed: U11.9 (A7), U13.142 (IOT_220)
unnamed: U11.10 (A8), U13.143 (IOT_221)
unnamed: U12.2 (A2), U13.60 (IOB_95)
unnamed: U12.9 (A7), U13.136 (IOT_214)
unnamed: U12.10 (A8), U13.137 (IOT_215)
unnamed: U13.45 (IOB_73), U15.2
unnamed: U13.102 (IOR_161), U14.11 (BLANK*)
unnamed: U13.104 (IOR_164), U14.24 (CLOCK)
unnamed: U9.28 (OE#), U13.134 (IOT_212)
PS2_CLK: U12.4 (A4), U13.55 (IOB_91)
PS2_DATA: U12.3 (A3), U13.56 (IOB_94)
RESETn: U2.18 (RESET), U12.20 (B1)
RX: U3.38 (BDBUS0), U13.61 (IOB_96)
R_Wn: U2.9 (R/W), U11.20 (B1)
TX: U3.39 (BDBUS1), U13.62 (IOB_102)
UDSn: U2.7 (UDS), U11.18 (B2)
VMAn: U2.19 (VMA), U11.15 (B5)
VPAn: U2.21 (VPA), U13.44 (IOB_72)
VSYNC: J4.14, U13.106 (IOR_166)
clk12: R21.1, U3.2 (OSCI), U13.21 (IOL_14A_GBIN6)
nHOLD: R11.1, U10.7 (~HOLD), U13.64 (IOB_104_CBSEL1)
nWP: R12.1, U10.3 (~WP), U13.63 (IOB_103_CBSEL0)

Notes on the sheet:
SRAM

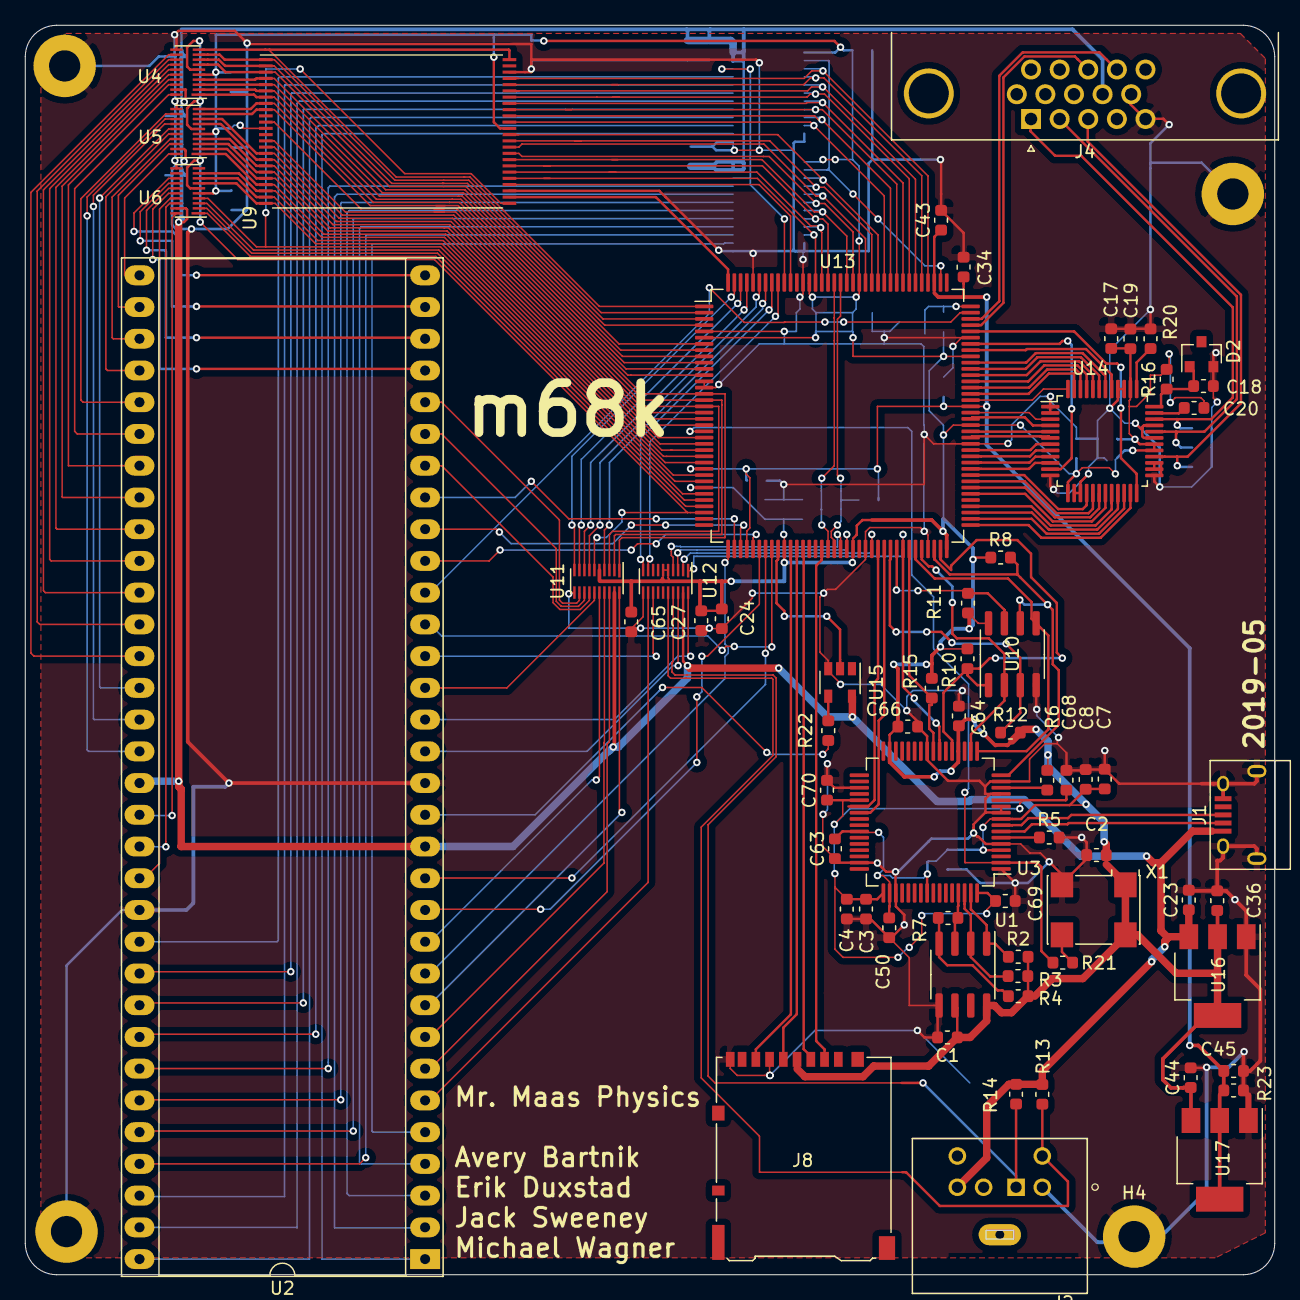
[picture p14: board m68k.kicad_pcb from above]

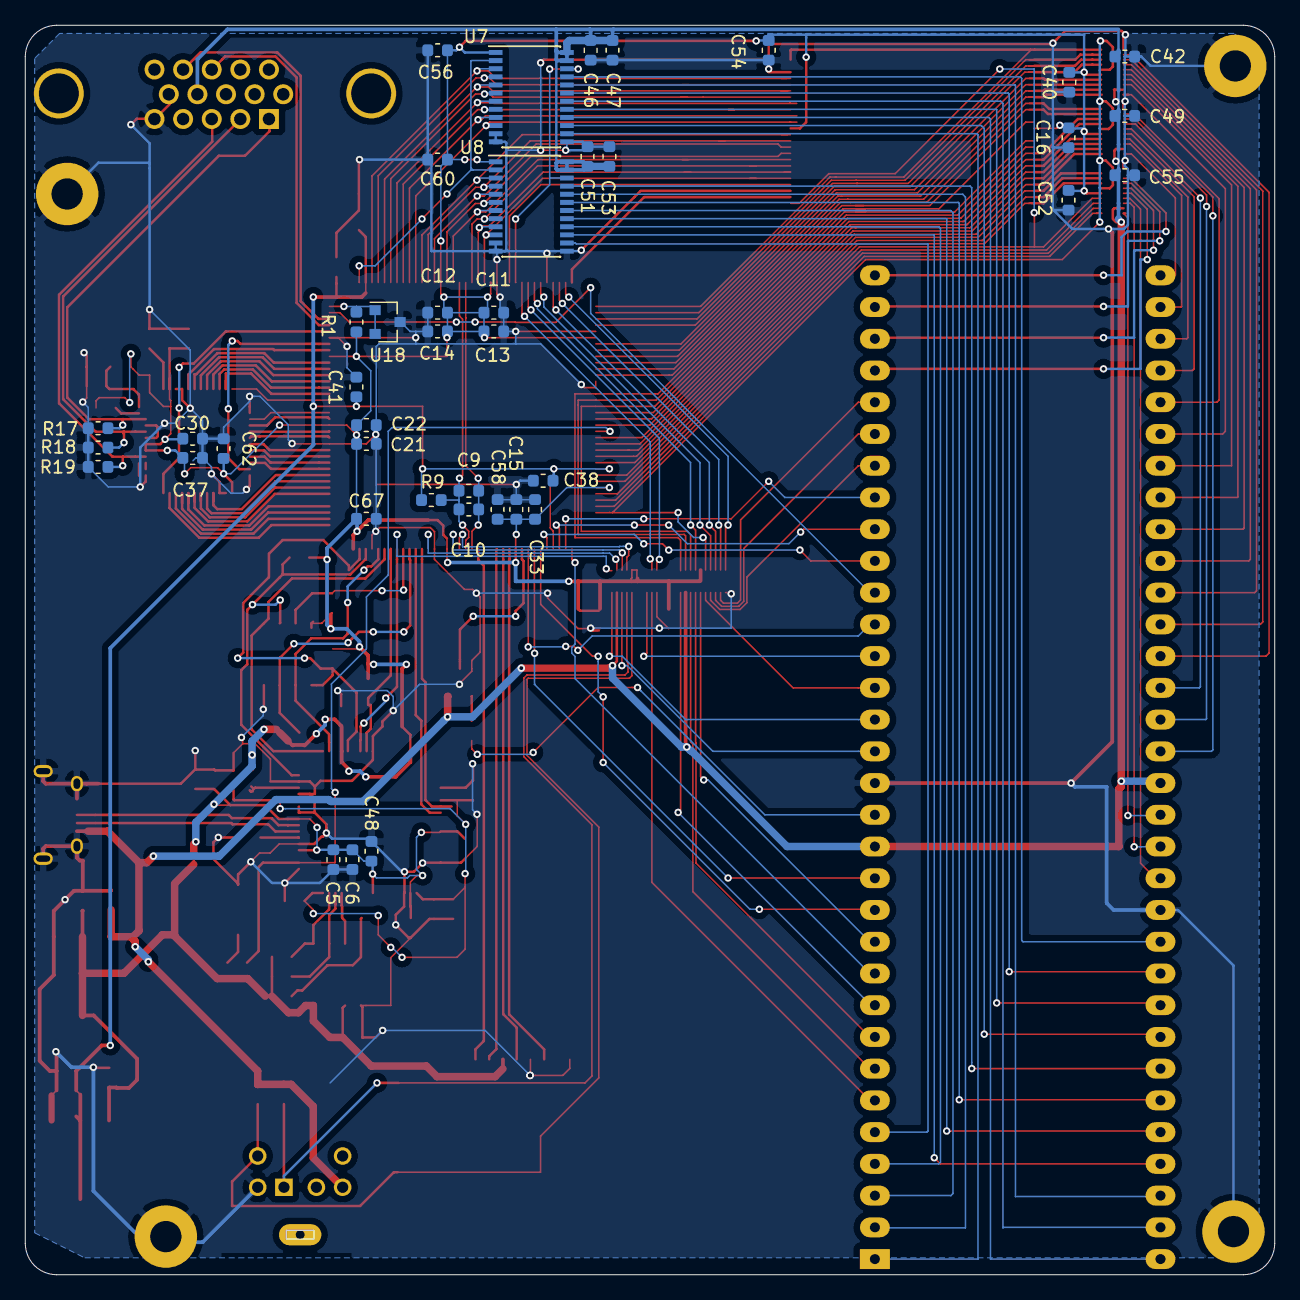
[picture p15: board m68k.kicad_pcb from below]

Board: 2 copper layers, 100.0 x 100.0 mm, 110 parts (41 on the bottom side), 187 nets.

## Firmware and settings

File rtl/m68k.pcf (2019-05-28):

set_io clk12 21
set_io CLK68000 45

set_io addr[1] 29
set_io addr[2] 28
set_io addr[3] 26
set_io addr[4] 25
set_io addr[5] 24
set_io addr[6] 23
set_io addr[7] 22
set_io addr[8] 20
set_io addr[9] 11
set_io addr[10] 10
set_io addr[11] 9
set_io addr[12] 8
set_io addr[13] 7
set_io addr[14] 4
set_io addr[15] 3
set_io addr[16] 2
set_io addr[17] 1
set_io addr[18] 19
set_io addr[19] 18
set_io addr[20] 12
set_io addr[21] 33
set_io addr[22] 32
set_io addr[23] 31

set_io data[0] 130
set_io data[1] 128
set_io data[2] 124
set_io data[3] 121
set_io data[4] 119
set_io data[5] 117
set_io data[6] 115
set_io data[7] 113
set_io data[8] 129
set_io data[9] 125
set_io data[10] 122
set_io data[11] 120
set_io data[12] 118
set_io data[13] 116
set_io data[14] 114
set_io data[15] 112

set_io ASn 137
set_io R_Wn 15
set_io UDSn 16
set_io LDSn 17
set_io DTACKn 37

set_io BRn 43
set_io BGn 138
set_io BGACKn 42

set_io IPLn[0] 38
set_io IPLn[1] 39
set_io IPLn[2] 41

set_io FC[0] 143
set_io FC[1] 142
set_io FC[2] 141

set_io E 136
set_io VMAn 139
set_io VPAn 44

set_io BERRn 107
#set_io RESETn
set_io HALTn 60

set_io DATA_OEn 135
set_io ADDR_OE 34
set_io DIR 110

set_io RX 61
set_io TX 62

#set_io [7:0] RX_data
#set_io [7:0] TX_data
#set_io TXE
#set_io TX_read

set_io SRAM_OEn 134
set_io SRAM_CEn 144

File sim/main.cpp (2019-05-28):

#include <iostream>
#include <ncurses.h>
#include "Vm68k_tb.h"
#include "verilated.h"
#include "testbench.h"

int main(int argc, char **argv) {
	Verilated::commandArgs(argc, argv);
	
	TESTBENCH<Vm68k_tb> *tb = new TESTBENCH<Vm68k_tb>();

	//tb->opentrace("dump.vcd");
	tb->reset();

	initscr();
	cbreak();
	noecho();
	nodelay(stdscr, TRUE);

	while(!tb->done()) {
		tb->tick();

		if (tb->m_core->RX_DV) {
			//addch(tb->m_core->RX_data);
			putchar(tb->m_core->RX_data);
			refresh();
		}

		if (tb->m_core->TX_active) {
			tb->m_core->TX_start = 0;
		} else {
			int c = getch();
			if (c != ERR) {
				tb->m_core->TX_data = c;
				tb->m_core->TX_start = 1;
			}	
		}
	}
	tb->done();
	endwin();
	return 0;
}

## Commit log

2019-05-15 Add KiCAD files
    [m68k.kicad_pcb, m68k.sch]
2019-05-16 start schematic
2019-05-17 add rtdi sd and ps2
    [m68k.sch]
2019-05-17 Cleanup schematic and fix errors
    [m68k.sch]
2019-05-17 add vga dac and start control pins
    [m68k.sch]
2019-05-17 Clean-up some signals
    [m68k.sch]
2019-05-19 Fix mostly everything
    [m68k.sch]
2019-05-19 Fix VBUS voltage
    [m68k.sch]
2019-05-19 Add various updates and import to Pcbnew
    [m68k.kicad_pcb, m68k.sch]
2019-05-19 Reordered U8 Pins
    [m68k.kicad_pcb, m68k.sch]
2019-05-20 Reorder SRAM Pins
    [m68k.sch]
2019-05-20 add test points and rearrange pins
    This branch needs to be checked to make sure I didn't mess anything up on the pcb. If so, you can merge it back into erik-dev, otherwise you'll have to update the schem and pcb manually
    [m68k-B_Cu.gbr, m68k-B_Mask.gbr, m68k-B_Paste.gbr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]
2019-05-20 Update footprints (Mini DIN for PS/2 still missing)
    [m68k.kicad_pcb, m68k.sch]
2019-05-20 start pcb layout
    [m68k.kicad_pcb]
2019-05-20 update io
    [m68k.kicad_pcb]
2019-05-20 Added board outline
    [m68k.kicad_pcb]
2019-05-20 arrange pcb
    [m68k.kicad_pcb]
2019-05-20 switch to micro sd
    [m68k.kicad_pcb, m68k.sch]
2019-05-20 fix vga pinout
    [m68k.kicad_pcb, m68k.sch]
2019-05-20 add ps/2
    [m68k.kicad_pcb, m68k.sch]
2019-05-20 change to 200x100
    [m68k.kicad_pcb]
2019-05-21 continue pcb layout
    [m68k.kicad_pcb, m68k.sch]
2019-05-21 continue routing
    [m68k.kicad_pcb, m68k.sch]
2019-05-21 good luck michael
    [m68k.kicad_pcb]
2019-05-22 SAVE ME -Kicad
    [m68k.kicad_pcb]
2019-05-22 Battle Bus
    [m68k.kicad_pcb, m68k.sch]
2019-05-22 We should have used EAGLE
    [m68k.kicad_pcb]
2019-05-22 vga struggle
    [m68k.kicad_pcb]
2019-05-22 WHERE'S ROUTING?
    [m68k.kicad_pcb, m68k.sch]
2019-05-22 pcb stuff
    [m68k.kicad_pcb, m68k.sch]
2019-05-22 Cleaned up CAPS
    [m68k.kicad_pcb]
2019-05-22 clean up pins
    [m68k.sch]
2019-05-23 I finally broke something
    [m68k.kicad_pcb, m68k.sch]
2019-05-23 almost finish routing
    [m68k.kicad_pcb, m68k.sch]
2019-05-23 silkscreen pass
    [m68k.kicad_pcb]
2019-05-23 Prepare for switching to Verilator
2019-05-24 pre pour
    [m68k.kicad_pcb, m68k.sch]
2019-05-24 Add carriage return in Hello World for ncurses
2019-05-27 Switch to proper UARTs transitioning to real hardware
2019-05-28 Update schematic PDF
2019-05-28 Add pcb layout editor images
2019-05-28 add PCB layout to gallery
2019-05-28 add schematic to gallery
2019-05-28 add link to assembly file
2019-05-31 update ps/2, usb, and mounting hole.
    [m68k.kicad_pcb, m68k.sch]
2019-06-01 update resistor value
    [m68k.kicad_pcb, m68k.sch]
